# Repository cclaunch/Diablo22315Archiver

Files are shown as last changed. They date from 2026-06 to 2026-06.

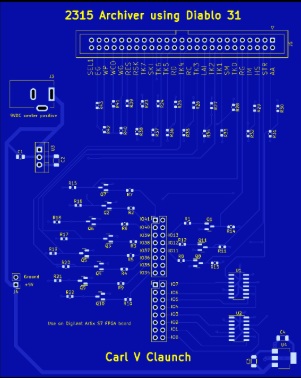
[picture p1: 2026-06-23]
board.jpg

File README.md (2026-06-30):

Diablo disk drive model 31, in its standard density version, can read or write to the 2315 disk cartridges interchanngeably with the disk drives in the IBM 1130 system 

This project exploits an FPGA board with a custom interface board to control the Diablo disk drive. It will read the contents of the disk cartridge into RAM on the FPGA board. 

It then uploads the contents over the USB serial link so that the contents can be archived. The software will take the data streaming over the USB link and create disk files 
in the format used with the IBM 1130 simulator programs (and therefore with the Virtual 2315 Cartridge Facility to access them on a real 1130 system. 

The PCB connects to the FPGA board, provides power to the FPGA and the logic on the PCB, and connects to the Diablo disk drive using an IDC 50 pin cable.

A PCB is available to create the Head Adapter Tool used in aligning a Diablo 31 standard density drive using the CE Cartridge

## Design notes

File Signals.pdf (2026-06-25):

Signal | Direction FPGA pin | Diablo | Connected IDC50 pin drive pullup terminator pcb term unused Option only
Strobe_L | T | 11 | SS | X | 4 | 220/510 | 10K
Head_Select_L | T | 12 | AA | X | 6 | 220/510 | 10K
Rd_Gate_L | T | 13 | E | X | 10 | 220/510 | 10K
Track7 | T | 34 | BB | X | 36 | 220/510 | 10K
Track6 | T | 35 | T | X | 32 | 220/510 | 10K
Track5 | T | 36 | FF | X | 30 | 220/510 | 10K
Track4 | T | 37 | X | X | 26 | 220/510 | 10K
Track3 | T | 38 | J | X | 22 | 220/510 | 10K
Track2 | T | 39 | RR | X | 18 | 220/510 | 10K
Track1 | T | 40 | N | X | 16 | 220/510 | 10K
Track0 | T | 41 | LL | X | 12 | 220/510 | 10K
Write_Clk_Data_L | T | 10K pullup | B | X | 44 | 120/300 | 10K | X
Restore_L | T | 10K pullup | VV | X | 40 | 220/510 | 10K | X
Write_Gate_L | T | 10K pullup | EE | X | 42 | 120/300 | 10K | X
write protect | T | 10K pullup | H | X | 46 | 220/510 | 10K | X | X
erase gate | T | 10K pullup | K | X | 48 | 220/510 | 10K | X | X
Select 4 | T | 10K pullup | Z | | | 220/510 | | X
Select 3 | T | 10K pullup | V | | | 220/510 | | X
Select 2 | T | 10K pullup | R | | | 220/510 | | X
Select 1 | G | ground | L | X | 50 | 220/510 | grounded
ground | G | ground | D, DD, WW | X | odd #s
Ready_Seek_L | F | 0 | F | X | 38 | 5V/10K | 120/300
Seek_Incomp_L | F | 1 | TT | X | 34 | 5V/10K | 120/300
Rd_Data_L | F | 2 | C | X | 28 | 3V/diode | 120/300 | 120/300
Rd_Clk_L | F | 3 | A | X | 24 | 3V/diode | 120/300 | 120/300
Log_Addr_Inlk_L | F | 4 | XX | X | 20 | 5V/10K | 120/300 | X
SM_L | F | 5 | W | X | 14 | 3V/diode | 120/300
IM_L | F | 6 | Y | X | 8 | 3V/diode | 120/300
Addr_Ack_L | F | 7 | NN | X | 2 | 5V/10K | 120/300
File_Ready_L | F | U | 5V/10K | X
Write_Check_L | F | HH | 5V/10K | X
Sector4 | F | UU | 5V/10K | X
Sector 3 | F | MM | 5V/10K | X
Sector 2 | F | KK | 5V/10K | X
Sector 1 | F | JJ | 5V/10K | X
Sector 0 | F | CC | 5V/10K | X

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
t in

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
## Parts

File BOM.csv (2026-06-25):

# | QUANTITY | VENDOR | DESCRIPTION | UNIT PRICE | EXTENDED PRICE | PART NUMBER | MANUFACTURER PART NUMBER
1 | 20 | Digikey | TRANS NPN 15V 0.2A SOT23-3 | $0.12 | $2.40 | MMBT2369ALT1GOSCT-ND | MMBT2369ALT1G
2 | 20 | Digikey | RES 330 OHM 5% 1/4W 0603 | $0.09 | $1.70 | 10-ERJ-UP3J331VCT-ND | ERJ-UP3J331V
3 | 10 | Digikey | IC BUFF 1.65V 14-SO | $0.23 | $2.33 | 74LVC125AS14-13DICT-ND | 74LVC125AS14-13
4 | 2 | Digikey | CONN HEADER VERT 16POS 2.54MM | $5.56 | $11.12 | 612-TD-108-G-A-ND | TD-108-G-A
5 | 1 | Digikey | IC REG LINEAR 3.3V 800MA SOT-223 | $1.57 | $1.57 | LM1117MP-3.3/NOPBCT-ND | LM1117MP-3.3/NOPB
6 | 1 | Digikey | CONN HEADER VERT 50POS 1.27MM | $2.79 | $2.79 | 2057-HBHR-A1-50-VG-HT-ND | HBHR-A1-50-VG-HT
7 | 5 | Digikey | CAP TANT 10UF 10% 16V 1206 | $0.47 | $2.35 | 478-8235-1-ND | F931C106KAA
8 | 5 | Digikey | CAP TANT 0.33UF 20% 20V 0805 | $0.34 | $1.70 | 718-2503-1-ND | TMCP1D334MTRF
9 | 5 | Digikey | CAP TANT 0.1UF 10% 20V 1206 | $0.89 | $4.45 | 478-TAJS104K020RNJCT-ND | TAJS104K020RNJ
10 | 1 | Digikey | CONN POWER JACK SOLDER 2.5MM | $1.02 | $1.02 | 2092-KLDHCX-0202-BC-1-ND | KLDHCX-0202-BC-1
11 | 2 | Digikey | CONN HEADER VERT 2POS 2.54MM | $0.68 | $1.36 | 612-TS-102-T-A-ND | TS-102-T-A
12 | 25 | Digikey | RES SMD 10K OHM 1% 1/10W 0603 | $0.02 | $0.38 | CR0603-FX-1002ELFCT-ND | CR0603-FX-1002ELF
13 | 10 | Digikey | RES SMD 120 OHM 5% 1/3W 0603 | $0.06 | $0.58 | P120BZCT-ND | ERJ-PA3J121V
14 | 25 | Digikey | RES 300 OHM 5% 1/3W 0603 | $0.05 | $1.36 | RHM300DCT-ND | ESR03EZPJ301
15 | 0.08333 | Amazon | LM7805CV voltage regulator | $6.41 | $0.53 | https://www.amazon.com/dp/B0C5M51R2Z?ref=ppx_yo2ov_dt_b_fed_asin_title&th=1
16 | 1 | Amazon | IDC 50 pin cable | 50cm long | $10.69 | $10.69 | https://www.amazon.com/dp/B07S9KRBDV?ref=ppx_yo2ov_dt_b_fed_asin_title
17 | 1 | ? | Diablo terminator |  |  | collectors or ebaty
18 | 1 | ? | Diablo model 31 standard density |  |  | collectors or ebaty
19 | 1 | Digilent.com | Artix S7 FPGA board | $127.33 | $127.33 | https://digilent.com/shop/arty-s7-spartan-7-fpga-development-board/
20 | 1 | Amazon | 9V power supply wallwart | $9.62 | $9.62 | https://www.amazon.com/dp/B087ZWS7CG?ref=ppx_yo2ov_dt_b_fed_asin_title&th=1
21 | 1 | PCBway | PCB manufactured from design | $174.99 | $174.99
22 | 2 | Amazon | Meanwell 15V 7A PS bought as pair | $19.71 | $39.42 | https://www.amazon.com/dp/B0CCYL43VT?ref=ppx_yo2ov_dt_b_fed_asin_title&th=1
23 | 1 | Amazon | Dual +/- 15V 2A supply | $30.17 | $30.17 | https://www.amazon.com/Output-Switching-Converter-Computer-24V1-6-24V1-6A/dp/B0DSFLLWTV
 |  |  |  | Total | $427.86

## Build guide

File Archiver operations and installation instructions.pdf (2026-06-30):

## Operations and Installation Instructions

2315 Archiver on Diablo 31 Drive

Carl V Claunch | 1 | Version 1

Archiving 2315 cartridges for the IBM 1130 System

The IBM 1130 System uses a single 14” platter disk cartridge (2315) inserted into an internal disk drive (13SD or Ramkit) or the optional 2310 external disk drive cabinet.

The 2315 cartridges record up to 512K words in sectors of 321 words each. The disk is organized into 203 cylinders, with an upper and a lower surface (track) per cylinder and having four sectors on each track. The platter is inside a protective plastic case.

The data is recorded at a rate of 720 kilobits per second while the disk platter spins at 1500 rpm. Thus data streams to and from the drive at 36K words per second during a read or write.

Each 16 bit word is recorded with four additional error checking bits. There is a mandatory preamble and a sync word at the start of each sector. The format for a sector is unique to the IBM 1130 and 1800 systems.

2315 Archiver on Diablo 31 Drive

Carl V Claunch | 2 | Version 1

IBM licensed disk drive technology to multiple companies

IBM offered licenses to other manufacturers who produced disk drives and disk cartridges based on the 13SD drive and 2315 cartridge designs. Several firms made disk cartridges and several developed disk drives for their minicomputer systems under license.

The 2315 cartridge used with the IBM 1130 has eight physical sectors around the circumference of the platter, but licensees made versions with other sector counts, up to 32. The platter is otherwise identical except for the metal hub with its sector mark notches.

The companies that licensed the disk technology were free to improve on the 13SD drive and most did. The IBM drive used a mechanical ratchet system for arm movement between cylinders, thus is moved in steps of 1 or 2 cylinders at a time. All the other manufacturers designed a servo system that supports a single move of any number of cylinders.

The rate at which data is clocked onto the platter - 720KHz in the case of the IBM drive - was implemented at higher rates of 781, 1440 and 1562 KHz by those makers. The two higher rates were labeled High Density.

Other versions doubled the number of cylinders on a pack by writing narrower tracks and moving in finer increments. A few added a second fixed platter underneath the place where the cartridge’s platter spins. Thus the licensees could achieve more than 16 times the data density of the 13SD and 2315 used in IBM 1130 systems.

2315 Archiver on Diablo 31 Drive

Carl V Claunch | 3 | Version 1

Diablo Model 31 Drives

Diablo Systems built their Model 30 series under license and in particular sold the Model 31 as the closest version to the IBM 13SD/2310. They offered many options - Model 31 could operate at any of the four data rates and make use of cartridges with 8, 12, 16, 24 or 32 sectors per revolution. Xerox PARC (Palo Alto Research Center) created their groundbreaking Alto computers using a high density model 31 drive.

Model 31 drives can be used with this project to read 2315 cartridges that were written on IBM 1130 systems, but must match the specifications of the 13SD drive. Thus, they must use 8 sector cartridges and have a data rate of 720KHz. If so, the Diablo drive and the 1130 can read data written on the other system, giving full interchangeability.

The Model 31 must have certain options listed to be compatible with the 13SD. Essentially, they must be a standard density version, at either 720KHz or 781KHz data rate.

Modifications to the printed circuit boards inside the Diablo drive can change a 781KHz drive into the desired 720Khz for compatibility, but option 001 (720KHz) works without modification. Details of the modification are provided later in this document.

Options26 39, 40, 41, 42, 51, 52, or 54 indicate drives that are based on more sectors than the 8 per revolution used with the IBM drives. The other options may slightly change the electrical interface but don’t affect the physical interchangeability of cartrdiges between IBM and Diablo.

2315 Archiver on Diablo 31 Drive

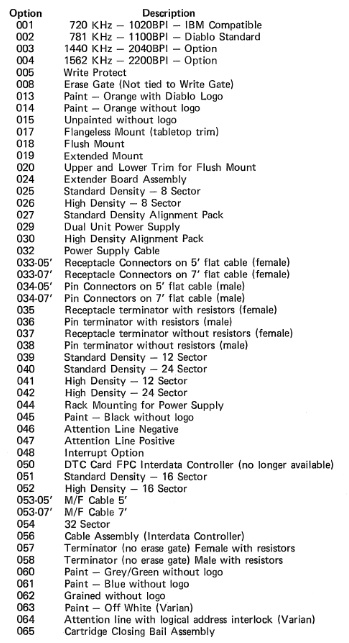
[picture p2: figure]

Carl V Claunch | 4 | Version 1

This is the full option list for Model 31 drives:

2315 Archiver on Diablo 31 Drive

Carl V Claunch | 5 | Version 1

Interface to Model 31 drive

The electrical interface to the Diablo model 31 differs from the IBM 13SD drive, mainly due to the change in arm movement between the IBM drive and the way that licensees like DEC, HP and Diablo implemented seeks.

The handshakes between the controller logic and the disk drive are different as well as having an absolute cylinder number and different movement command signals. Thus this cannot use the logic designed to read or write on the 13SD drives.

The Diablo drives can be daisy chained with up to four drives connected to a single controller, making use of four Select signals to control which drive is active at any instant. A terminator is installed on the back of the last drive in a chain. Terminators vary based on some options, thus when using this project, the builder must verify that the critical signal lines have termination resistors; the terminator must be modified if it does not match.

This project includes a printed circuit board that supports the electrical requirements of the interface to the Diablo Model 31, including termination resistors for the controller side of the cable. A standard 50 pin IDC connector (e.g an internal SCSI cable for a PC) is used to connect a cable from the PCB to the connection block of the Diablo Model 31 disk drive. This requires changes to the cable and connection of the wires in the cable to the proper pins on the disk drive.

2315 Archiver on Diablo 31 Drive

Carl V Claunch | 6 | Version 1

Components of the archiver project

A suitable Diablo Model 31 disk drive is required. A terminator and a signal connector are also needed, although the connector will be modified in all cases.

A Digilent Artix A7 FPGA board with the bitstream from this project loaded onto the board to implement the logic of the project.

A custom PCB installed on top of the FPGA board to provide the electrical interface between the FPGA and the Diablo drive.

A modified 50 pin IDC flat ribbon cable runs between the PCB and the Diablo drive connector.

A USB cable to provide a serial link to a PC, Mac or other computer where the data extracted from the 2315 cartridge can be uploaded.

A Python application that connects to the archiver and creates disk files in the format used by the IBM 1130 simulator programs. This is the standard for interchange of disk cartridge images.

2315 Archiver on Diablo 31 Drive

Carl V Claunch | 7 | Version 1

Operating the Archiver

With the disk drive and the power supply of the Archiver both plugged into the building AC mains, the device is ready to perform archiving.

It is highly recommended to open each 2315 cartridge before reading it, inspecting for damage, and cleaning the surfaces with 91% Isopropyl Alcohol and low/no lint wipes. This minimizes the risk that you will suffer a head crash which scapes up the disk heads in the Diablo drive and perhaps damages the 2315 cartridge platter.

Eight screws around the bottom of the cartridge are removed to open the cartridge case and expose the platter inside. Use disposable gloves when handling the platter as a fingerprint is high enough to cause a head crash if you touch the surface of the platter

The heads should also be inspected with a dental mirror before archiving each cartridge, looking for the buildup of oxide or signs of a head crash. Low lint swabs with 91% Isopropyl Alcohol can be used to clean the heads, although with crashes it may be necessary to remove the heads for a more complete cleaning and then perform an alighment on reinstallation.

Insert the cartridge into the Diablo drive and switch on the drive. I recommend repeatedly spinning the drive for about 30 seconds and shutting down to ensure all dust is removed first. The drive has a HEPA quality filter that should clean the air going into the cartridge, but it may take some time to get all residual dust out before we want to load the heads.

The cartridge should come up to speed and after 50 seconds, the Ready lamp on the drive illuminates indicating that the heads have been lowered onto the spinning disk surface.

2315 Archiver on Diablo 31 Drive

Carl V Claunch | 8 | Version 1

With the righrmost slide switch SW0 on the FPGA board set to the lower position, push the rightmost button BTN0 to begin the archiving process. LEDs will light with various status and error conditions - see the troubleshooting section later for details.

You will hear the Diablo drive moving the disk arm cylinder by cylinder as it reads all 203 cylinders into memory on the board. When it is complete, power down the Diablo drive and remove the 2315 cartridge.

Start the python application, choose a file location and name for the archived disk image, and wait until the application tells you it is ready.

Move slide switch SW0 to its top position and then push the button BTN0 to start the upload process. When the contents have been successfully loaded, the application will indicate success and you can move the rightmost slide switch back to the bottom position to prepare for the next cartridge to be archived.

The application will report any sectors that experienced data errors during the archiving. Since cylinders 200, 201, 202 and 203 are reserved as alternate cylinders for any of the first 200 that might have imperfections, you may see errors on some cylinders that were either defective or alternates that were not used nor formatted.

Note any errors just in case some content of the cartridge was not recovered properly. Deal with the error sectors manually using an IBM 1130 simulator and disk utilities, after first excluding defective and unused cylinders.

2315 Archiver on Diablo 31 Drive

Carl V Claunch | 9 | Version 1

Building the cables between the archiver PCB and the Diablo drive

On the rear of the Diablo drive are a pair Winchester MRAC 42 plug and socket connectors and a Winchester MRAC-14S socket. The 42 pin parts are for signals while the 14 pin part delivers power.

Power connector

The power connector has letters A to F, H, J to N, P and R arranged left to right, from top to bottom looking at the face of the connector. Connect ground to pin C, high current (4A average 8A peak) +15V power supply to K, high current (4A average 8A peak) -15V power supply to R, low current +15V supply to H and low current -15V power supply wire to P. Use 16 ga wire for power and at least 15ga braid ground wire.

Noise generated by motors and servos will be fed back on the high current supplies, which is why a separate low current version is needed for signaling and logic.

Signal connector

There is a 42 position male (pins) and a female (sockets) connector on each drive. The terminator assembly is connected to one of them and the cable to the archiver connects to the other. The corresponding pins of both connectors are wired together thus the only difference is gender.

The connectors can be found on eBay, both the 42 pin shell and the male or female inserts for each position. Take a 50 cm 50 wire flat ribbon cable that has the IDC (internal SCSI) connectors installed. Remove on of the two IDC connectors and separate the wires. Every other wire in the cable is connected to ground on the archiver PCB.

2315 Archiver on Diablo 31 Drive

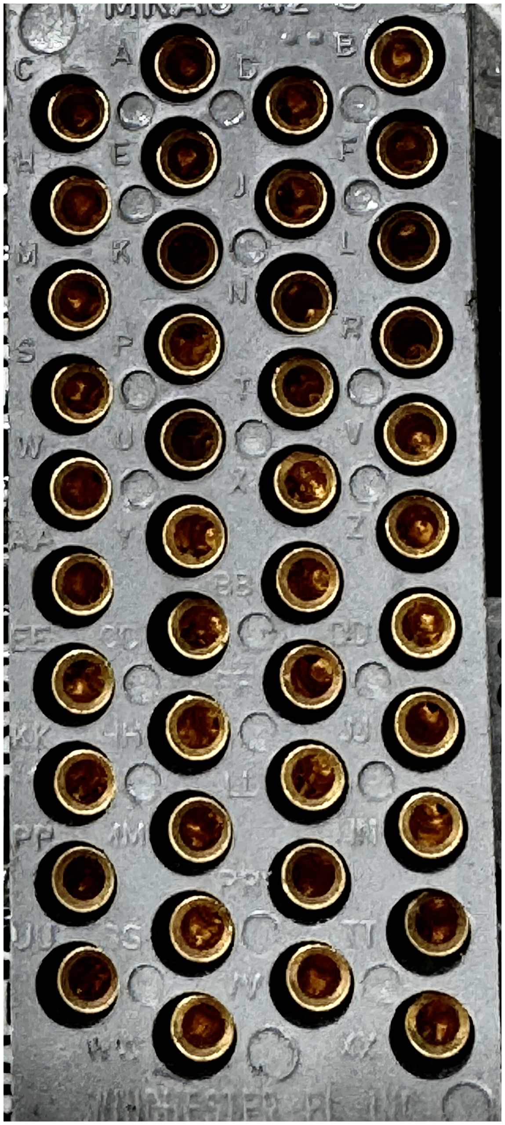
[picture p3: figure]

Carl V Claunch | 10 | Version 1

The positions on the MRAC connector are labeled with single or double letter codes - A to F, H, J to N, P, R to Z, AA to FF, HH, JJ to NN, PP, and RR to XX running left to right, from top to bottom as you look at the male connector face.

2315 Archiver on Diablo 31 Drive

Carl V Claunch | 11 | Version 1

Connect wires 1 and 3 to pin D, wires 23 and 25 to pin DD and wires 47 and 49 to pin WW which establishes the ground connection to the drive. Then connect the following wires to these pins:

2 | - NN
4 | - SS
6 | - AA
8 | - Y
10 - E
12 - LL
14 - W
16 - N
18 - RR
20 - XX *
22 - J
24 - A
26 - X
28 - C
30 - FF
32 - T
34 - TT
36 - BB
38 - F
40 - VV
42 - EE
44 - B
46 - H *
48 - K *
50 - L

Wires 46 and 48 are attached only if the write protect (option 005) and erase gate (option 008) are installed on this drive.

If options 046, 047 or 064 are installed, do not connect wires 20 and 46.

2315 Archiver on Diablo 31 Drive

Carl V Claunch | 12 | Version 1

Power supply sourcing

The drive requires four separate power supplies, two at +15VDC and two at -15VDC. One of each is a high current version, delivering a steady 4A with temporary bursts as the motor starts to spin. The other two deliver 2A of current for the logic and analog circuits that need to be free from the noise and impedance effects of the heavy current loads.

I bought three supplies, two are high current single voltage and the third delivers both +15V and -15V at lower current. These connect to the 120VAC mains. I found these on Amazon.com and should have them in a few days so that I can spin up the drive.

2315 Archiver on Diablo 31 Drive

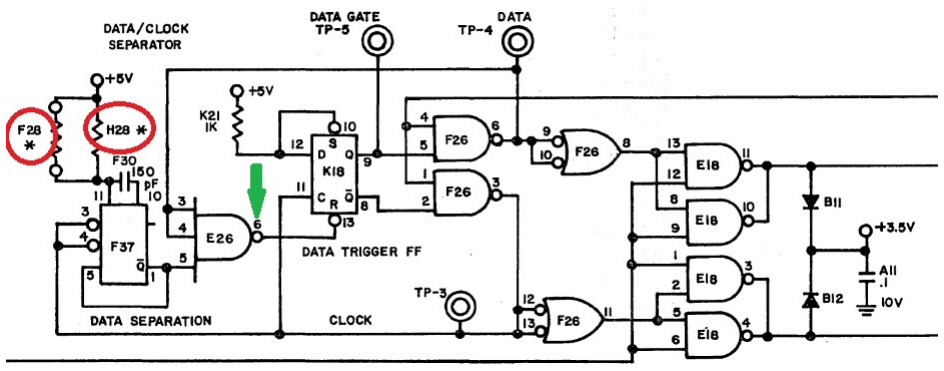
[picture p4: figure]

Carl V Claunch | 13 | Version 1

Modifying the Diablo Model 31 if option 002 (781KHz)

Pull out PCB J10 from the Diablo Model 31 drive’s card cage. Verify it is the Standard Density version, not the 1440 or 1562KHz high density alternative which has a board number of 11082-xx.

The PCB board number will be 11113-04, 11113-05, 11113-06 or 11113-07 if it is the standard density 781KHz data rate board.If the PCB number is 11113-00, 11113-01, 11113-02 or 11113-03 then it is already the IBM compatible 720KHz design.

The four subtypes depend on if there is an independently controlled Erase Gate signal (option 008)and if it is designed for daisy-chaining up to four drives from the controller. The first and second are for machines with no daisy chain, which means no Selection jumper used; I have never seen one without daisy chaining. Thus you have the fourth type if option 008 is installed, otherwise the third type.

To convert the data rate down from 781KHz to 720KHz, you change the resistor at H28 from a 9.08K to a 10K 1/2W 5% part. You then trim the resistance by selecting a high value parallel resistor F28 so that the data gate signal, the output of gate E26, is high between 955 and 985 nanoseconds duration. The faster board had a shorter gate duration (882-912ns).

2315 Archiver on Diablo 31 Drive

Carl V Claunch | 14 | Version 1

Troubleshooting

The FPGA board has eight LEDs that provide status information about the archiver operation - LD4 to LD7 are single color while LD0 to LD3 are tricolor and can show up to three signals per LED.

Displayed in both archive and upload

LD0 has red on head 1 is selected, off if head 0 LD0 has green on if the sector number is odd LD0 has blue on if the sector number is 2 or 3

LD1 is blue if the arm is at cylinder 0 to 22 LD1 is green if the cylinder is 23 to 45
LD1 is red if the cylinder is 46 to 68

LD2 is blue if the cylinder is 69 to 91
LD2 is green if the cylinder is 92 to 114 LD2 is red if the cylinder is 115 to 147

LD3 is blue if the cylinder is 148 to 170
LD3 is green if the cylinder is 171 to 193
LD3 is red if the cylinder is 194 to 203

The signals displayed can vary based on the position of the rightmost slide switch SW0 where the down position is during archiving and the up position is during upload of the captured disk image.

2315 Archiver on Diablo 31 Drive

Carl V Claunch | 15 | Version 1

Displayed during archiving

LD4 illuminates after power-on of the FPGA once the dynamic RAM on the board has finished its initialization and calibration. If this is not on, the archiver will not do anything.

LD5 is lit when the driver reports a logical address interlock - a seek attempt to a cylinder beyond 203. Most drives do not have this signal active so this would never light on those

LD6 is lit when a seek to a cylinder fails, which results in the drive becoming locked until it is power cycled. This is a hardware failure.

LD7 is lit when the archiving is complete - all 1, 632 sectors have been read and saved in RAM.

Displayed during uploading

LD4 illuminates when the FPGA has initialized and calibrated RAM so that it is ready to work. If this is not on, no other function works.

LD5 is lit when the upload process has completed, transferring all 1, 632 sectors of data over the USB serial link.

LD6 should not light in upload. It indicates that the disk drive suffered an error during a seek and has locked up, requiring power cycling.

LD7 is lit if the prior archiving process completed

2315 Archiver on Diablo 31 Drive

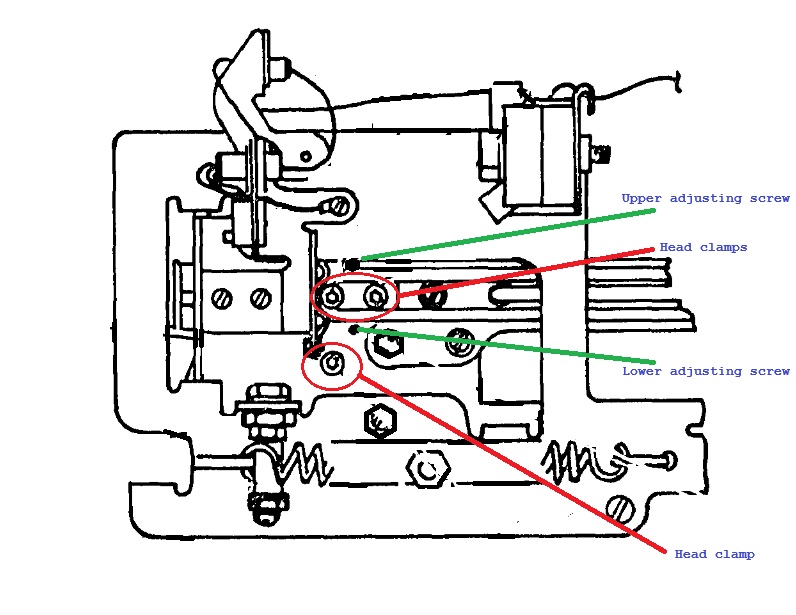
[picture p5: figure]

Carl V Claunch | 16 | Version 1

Adapter board to support alignment of the Diablo disk drive

The heads of the disk drive are attached to an arm that is moved in and out to reach each of the 203 cylindrical recording positions on the platter. When a head is installed, it must be adjusted so that it rides precisely over the intended track on the platter. This is important to allow data written on one disk drive to be successfully read from another drive.

A special 2315 cartridge, called the CE Cartridge, has a special pattern recorded at cylinder 100 which is used to fine tune the location of the head, using an oscilloscope to watch the signal returned from the read circuitry.

The heads are clamped in place and have a diagonal notch that a setscrew pushes into that will force the head slightly forward with each turn of the screw.

However, in order to maximize the visibility of the pattern on the scope, standard density heads needed to use the erase coil of the head, whose magnetic poles were further apart than the read/write coils.

2315 Archiver on Diablo 31 Drive

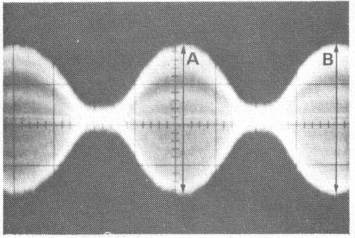
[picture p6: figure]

Carl V Claunch | 17 | Version 1

To switch over to using the erase coils, a special adapter is plugged into the drive, sitting between the cable from the heads and the J10 printed circuit board that contains the read amplifiers. This was called the Head Adapter Tool and I have never seen one of these in the last decades.

I designed a small PCB to act as a Head Adapter Tool. Its design is included in the project, allowing anyone with a Diablo standard density drive and a CE cartridge to complete the alignment procedure as defined by Diablo.

The alignment is complete when the signal pattern, consisting of multiple lobes and null points, displays lobes with as close to identical amplitudes as possible. That indicates that the head is right over the centerline of track 100.

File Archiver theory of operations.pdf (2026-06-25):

## Theory of Operation

2315 cartridge archiver using Diablo 31

Carl V Claunch | 1 | Version 1

Summary

This project employs a Diablo Systems model 31 disk drive of either 720 Khz or 781 KHz data rate to read the contents of 2315 disk cartridges that were used on an IBM 1130 system. It then uploads the archived contents over a USB serial link to an application running on a PC, Mac or other computer that will store the disk image in the format used with the IBM 1130 simulators.

This is based around a Digilent Arty A7 FPGA board, having a Xilinx Artix A7 FPGA, plenty of dynamic RAM, buttons, switches, LEDs and quite a few input-output connections.

A custom printed circuit board is plugged into the top of the Arty A7 board. It is powered by a wall wart 9V DC supply and in turn feeds the appropriate power to the circuits on the PCB as well as to the FPGA board. The board interfaces with the voltage, impedance and current requirements of the Diablo disk drive on one side and the FPGA board on the other.

A 50 pin IDC connector on a flat ribbon cable, modified on one end to connect to the Diablo drive Winchester MPAC-42 connector, carries signals between the custom PCB and the drive.

Three 120V power supplies deliver the +15V and -15V power to the high current and low current connections on the disk drive using a Winchester MPAC-9 connector. A USB cable connects the FPGA board to the remote computer that is running the Python application supplied with the project.

2315 cartridge archiver using Diablo 31

Carl V Claunch | 2 | Version 1

IBM 13SD disk drive as used in the IBM 1130

The IBM 1130 System uses a single 14” platter disk cartridge (2315) inserted into an internal disk drive (13SD or Ramkit) or the optional 2310 external disk drive cabinet.

The 2315 cartridges record up to 512K words in sectors of 321 words each. The disk is organized into 203 cylinders, with an upper and a lower surface (track) per cylinder and having four sectors on each track. The platter is inside a protective plastic case.

The data is recorded at a rate of 720 kilobits per second while the disk platter spins at 1500 rpm. Thus data streams to and from the drive at 36K words per second during a read or write.

Each 16 bit word is recorded with four additional error checking bits. There is a mandatory preamble and a sync word at the start of each sector. The format for a sector is unique to the IBM 1130 and 1800 systems.

IBM software systems use only 200 cylinders for the data. The remaining four cylinders are spares. When the disk cartridge is being initially formatted, if testing determines that a spot on a cylinder cannot successfully write and read back data, the cylinder is marked as defective and one of the four spares is assigned instead.

The software using the cartridge reads the table of possible alternate cylinders when the cartridge is first mounted, then converts any movement to the defective cylinder to the assigned alternate.

The disk arm has two heads, one for each side of the 14” platter. It can move outward towards cylinder 0 or inwards towards cylinder 203, but only in steps of 1 or 2 cylinders from its current location. A microswitch confirms when the arm has reached cylinder 0 (the home cylinder).

2315 cartridge archiver using Diablo 31

Carl V Claunch | 3 | Version 1

Moving the arm involves setting the step size (-10mil) and direction (-Reverse) signals, then commanding a movement (Access Go). Feedback signals (Access Ready) indicate that the drive has begun the movement and then tells us when the arm is steady at the new cylinder.

Notches cut around the circumference of the disk cartridge hub define the beginning of each pie shaped slice of the platter. There are eight notches however the 1130 controller converts those eight sectors into four larger sectors which is what the software sees when it uses the drive.

Pulses arrive on the interface - a Sector Marker - when we reach each notch. A separate notch defines the start position. This is the Index Marker and lets us know that the next sector is to be considered sector 0.

The interface has a control signal called Read Gate which switches on the electronics to deliver pulses coming from the head as it rotates through the sector. The data on the sector is recorded serially at a rate of 720 KHz.

The drive uses a self clocking scheme since all we see from the disk surface is when the magnetic field is reversed.

2315 cartridge archiver using Diablo 31

Carl V Claunch | 4 | Version 1

Reading if using the 13SD drive

If we wanted to read the contents of the disk cartridge using the 13SD drive, we would access it via its simple interface. For simplicity of understanding, you can consider the 720KHz clock to be divided into two halves - high then low.

During the high portion of a clock cycle, we always record a magnetic reversal. This is the clock pulse. During the low portion of the clock cycle, we either record another magnetic reversal or we leave that spot along. If the reversal comes in the low portion of the clock, we term this a data bit value of 1. No reversal in the low portion means that we have a data bit value of 0.

The beginning of every sector consists of a long stream of 0 data bits -each having a reversal only in the high portion of the clock. The long stream allows the drive electronics to synchronize to this pattern and begin splitting the reversal pulse out over two different output lines.

The clock pulse comes out on the Read Clock interface line, while any pulses from the low portion of the clock cycle are emitted on the Read Data line. We can watch for any data pulse that occurs betweee successive clock pulses and consider that a data bit value of 1, otherwise when we see the next clock pulse we consider that we received a data bit value of 0.

This self-synchonizing scheme tells us how to split clock and data pulses as they are picked up by the read head, but we don’t yet have a way to identify the first bit of an 1130 word. The 1130 uses 16 bit long words, thus we are extracting 16 data bit values to form a word.

2315 cartridge archiver using Diablo 31

Carl V Claunch | 5 | Version 1

For error checking purposes, the controller logic actually records 20 bits for each word. The last four bits are a value that brings the count of 1 data bits in the word to an even multiple of four. If the 16 bit 1130 word was already at an even mulitple of four - for example values x0000, x0238 and xffff have 0, four and sixteen 1 bits thus all are an even multiple of four. Our check bits would be 0000

The check bits are emitted to bring the count of 1 bits up to 0 modulo 4. For example, if we had the word x8000 with a single 1 bit, then the first three check bits are 1 and the last is 0, bringing the count up to 4.

To know when we are beginning a word recorded as 20 bits, we need to delineate when the first data bit would occur. that could be a 0 data value or a 1, so we have a special word value which is the first word recorded after the long string of 0 data bits. This word is x0001 with check bits 1110.

The logic reading from the drive turns on the Read Gate when we reach the sector, waits for a while to let the string of 0 data bits syncrhonize the clock/data splitter, then we watch for a data word that is the bit pattern 00000000000000011110 and the very next data bit will be the first bit of the first word of the sector.

The sector has up to 321 words of data recorded on it - 6,420 clock pulses, which we can now separate into words because we are synchronized. Typically we turn off the Read Gate after we read the last word. The 1130 can request from 1 to 321 words to be read, thus that count is used to decide when to turn off the Read Gate. For most purposes the 1130 reads all 321 words of a sector.

2315 cartridge archiver using Diablo 31

Carl V Claunch | 6 | Version 1

We have a Head Select signal that tells the drive to read or write from either the top head or the bottom head. Each head rotates past four sectors during one revolution of the disk drive. By reading four sectors on one side, switching the head and then reading another four sectors, we can read all 2,568 words of that cylinder.

Setting the direction and step size first, we can ask the disk drive to move the arm its 1 or 2 cylinders. When the feedback tells us we are at our new cylinder location, we can read or write the sectors at that arm position.

Writing new contents into a sector involves using the Write Gate, Erase Gate and the Write Clock & Data signal lines. When the Sector Mark indicates we are at the intended sector position, we turn on the Write and Erase Gate lines. We begin emitting a string of pulses on the Write Clock & Data signal line at 1,440 KHz rate. We alternate a clock pulse with either a data pulse or no pulse, so that we are generating the self clocking stream of magnetic reversals on the disk.

We begin by sending out only pulses for the clock portion, thus we write a long string of 0 data bits. When ready, we write a stream of pulses on
Write Clock & Data - 1 0 1 0 1 0 1 0 1 0 1 0 1 0 1 0 1 0 1 0 1 0
1 0 1 0 1 0 1 0 1 1 1 1 1 1 1 1 1 0 - which represents data bit val-
ues 0 0 0 0 0 0 0 0 0 0 0 0 0 0 0 1 1 1 1 0 or our sync pattern
word. We then write out the data words, first the sixteen data bit values as either 1 1 or 1 0 depending on the bit value, followed by the check bit pattern to bring our count of 1 value data bits to an even multiple of four.

When we have written the last word we want on that sector, we turn off the Write Gate and the Erase Gate control lines. Typically, all 321 words are written to a sector by 1130 software.

2315 cartridge archiver using Diablo 31

Carl V Claunch | 7 | Version 1

The only other signals on the interface are File Ready - the drive is ready to read/write/seek - a 720KHz clock which is generated in side the disk drive, and a 90 second delay signal that lets us know that the drive started but has not yet allowed enough time to purge any dust or contaminents from the surface of the disk. After 90 seconds the drive lowers the heads onto the disk surface and they ride at cylinder 0 waiting for commands over the interface.

2315 cartridge archiver using Diablo 31

Carl V Claunch | 8 | Version 1

Diablo Systems model 31 disk drive

IBM offered licenses to other manufacturers who produced disk drives and disk cartridges based on the 13SD drive and 2315 cartridge designs. Several firms made disk cartridges and several developed disk drives for their minicomputer systems under license.

The companies that licensed the disk technology were free to improve on the 13SD drive and most did. The IBM drive used a mechanical ratchet system for arm movement between cylinders, thus is moved in steps of 1 or 2 cylinders at a time. All the other manufacturers designed a servo system that supports a single move of any number of cylinders.

The rate at which data is clocked onto the platter - 720KHz in the case of the IBM drive - was implemented at higher rates of 781, 1440 and 1562 KHz by those makers. The two higher rates were labeled High Density.

Diablo Systems was one of the companies that built drives which were used by computer makers such as Xerox, Varian, and Interdata. Other companies such as DEC and HP licensed the technology and made their own drives.

The Diablo Model 31 comes in many flavors, described by the Options configured on the drive. Option 001 was for standard density 720KHz operation, also called IBM compatible.

Model 31 could operate at any of four data rates (720KHz, 781KHz, 1440 KHz and 1562KHz) and make use of cartridges with 8, 12, 16, 24 or 32 sectors per revolution. Xerox PARC (Palo Alto Research Center) created their groundbreaking Alto computers using a high density model 31 drive.

2315 cartridge archiver using Diablo 31

Carl V Claunch | 9 | Version 1

Using Diablo drive to read 1130 cartridges

Model 31 drives can be used with this project to read 2315 cartridges that were written on IBM 1130 systems, but must match the specifications of the 13SD drive. Thus, they must use 8 sector cartridges and have a data rate of 720KHz. If so, the Diablo drive and the 1130 can read data written on the other system, giving full interchangeability.

We provide a way to modify a Model 31 from Option 002 - 781KHz data rate - so that it can operate at the 720KHz rate. The higher density options use a different kind of read/write head and are incapable of interchanging data with the 13SD drive.

The interface of the Diablo Model 31 is more complex than the 13SD, plus there are many options to suit the many manufacturers who used these drives with their computers. A key difference is in how the disk arm is moved to a desired cylinder.

The Diablo interface has a set of eight signal lines (Track) that specify an absolute cylinder location. It does not have a direction or a step size. Instead, the interface is given the destination cylinder and then the Strobe signal is activated to request the movement. No home cylinder microswitch signal is included because the drive always knows here it is.

The feedback mechanism for a seek is a bit more complex - with timing requirements for when the Ready to Seek, Read or Write signal must drop and when it turns back on at the end of a movement. An Address Acknowledgement signal is sent to inform the computer that the drive has accepted the movement request.

Failure of the seek mechanism is indicated by Seek Incomplete. Requests to move to a cylinder beyond 203 can trigger a Logical Address Interlock signal if that option is included on the drive.

2315 cartridge archiver using Diablo 31

Carl V Claunch | 10 | Version 1

Sector Mark and Index Mark pulses are generated just like wtih the 13SD. However, this does require that the drive is configured for 8 sectors and the 2315 Disk Cartridge is 8 notches cut around the hub. Diablo also supports 12, 16, 24 and 32 sector formats which are incompatible with IBM.

Besides the use of the Sector Mark and Index Mark pulses, the interface offers a five bit Sector Number field that reports the upcoming sector number directly. There is also a Pseudo-Sector Marksd which emits pulses at a 50KHz rate so that a computer interface can calculate its own logical sector lengths, disregarding the phsical notches.

Reading and writing are controlled in very similar ways to the IBM 1130. Read Gate and Write Gate are used the same way. Erase Gate is normally activated automatically when Write Gate is asserted, but an option exists to control them individually. Head Select is used to swtich between the upper and lower sides of the platter.

The drive uses the same self-clocking scheme as the 13SD, thus pulses come out on the Read Clock and Read Data signals just as they do with IBM drives. Writing involves sending the mixed clock and data pulses on Write Clock & Data, again just like the 1130.

There are some signal options such as Write Protect which blocks the drive from erasing or writing, Write Check indicates a failure of the writing electronics and locks up the drive. Restore which brings the arm back to Cylinder 0 and resets any drive error condition.

Finally, the Diablo drives can be daisy-chained off a single disk controller, with up to four drives connected. The interface has signals Select 1, Select 2, Select 3 and Select 4 to allow the controller to choose which drive should respond to its commands. Interrupt and attention signals are also options but only rarely found on the drives.

2315 cartridge archiver using Diablo 31

Carl V Claunch | 11 | Version 1

Logic in the FPGA

Besides offering a boatload of logic elements, the Arty A7 board has 256MB of DDR3 DRAM which is very handy to store the contents of a disk cartridge which itself holds only 1MB of data. The onboard clock crystal runs at 100 MHz, far faster than any events happening on the disk drive (or even in the IBM 1130).

I set up a clock generator to produce the faster clocks required by the DDR3 memory controller intellectual property. In addition to the memory interface IP and the clock IP, I defined two FIFO queues using IP that exploits the native FIFO hardware on the FPGA chip. This is because the memory interface runs at a different clock rate than the general 100MHz logic of my design, thus the FIFO allows the data to cross clock domains safely. The memory interface produces the ui_clk clock used to drive the memory interface.

All external signals run through a chain of four flipflops to protect against metastable states since the timing of signal changes externally is unrelated to the clock edges inside the FPGA. I then pass the through a Schmitt Trigger module I wrote so that brief waggles in signals don’t cause the logic to switch states at the wrong time.

Everything I coded is in Verilog, although the IP and some borrowed modules may be in VHDL. In some ways, it is influenced by the RK05 Emulator code. I split the design into functional modules such as read a sector, seek to a cylinder, track the sector position, and then higher level modules that drive the process of archiving by moving serially through all 1,634 sectors across 203 cylindere.

2315 cartridge archiver using Diablo 31

Carl V Claunch | 12 | Version 1

The top level module just routes signals to the various functional modules and externally. to the interface board. It displays status on the eight LEDs and uses a slide switch and a button to request the archive step and then the upload across the the USB serial link.

Archiver module

The archiver logic starts off at cylinder 0, upper head, sector 0 and word
0. When the button is pressed to start the state machine, it advances through the states until it has completed reading all 1,634 sectors and 521,304 words and storing them into the RAM.

It loops waiting for the sector number to change to the target number, then kicks off the bus_read_drive module to read the sector. When that module responds with a completion signal, the state machine advances.

The next step advances through sectors, from 0 to 1 to 2 to 3, then returns to wait for that sector to arrive. When sector 3 has finished its read, the next step switches the head to the other platter and resets the sector target to 0. It then returns to wait for the sector.

After we finish sector 3 of the second head, we move to a step that advances the cylinder by 1, resets the head and the sector before returning to wait for the sector.

When we have finished the last sector, instead of going back like we did for the first 202 cylinders, we turn on a feedback signal indicating we are done with archiving and then reset to the idle state until we get a new request for archiving.

2315 cartridge archiver using Diablo 31

Carl V Claunch | 13 | Version 1

Sector and Index module

The module watches for the leading edge of the Sector Marker and Index Marker pulses to track the position of the platter as it rotates. It must swallow every other Sector Marker because that is how the 1130 controler logic converts the eight physical sectors into four logical one. The module emits the upcoming sector number to the other modules and a pulse when the Sector Marker leading edge arrives to start that sector.

Seek to Cylinder module

The state machine matches the timing spec of the Diablo model 31 drive. When a Strobe request arrives, the state machine first emits the new Track number to the drive. It then waits for Addr_Ack to be asserted by the drive, then loops for 3 microseconds. After that time, it resets the Track number. The state machine then drops the Strobe signal and waits for the drive’s Ready_Seek to go low, then returns to the idle state.

2315 cartridge archiver using Diablo 31

Carl V Claunch | 14 | Version 1

Bus_Read_drive module

When a requestread signal arrives to read a sector and store the words into the DRAM, the state machine waits for the leading edge clkenable_sector pulse from the Sector and Index module that indicates we reaached the start of a sector.

The first state raises the Read_Gate signal and sets up to wait rhrough reading 100 bit values of 1 from either the Read Clock or the Read Data lines. The preamble should be a long string of clock pulses with no data pulses which allows the drive to properly split pulses as clock or data.

After we see 100 pulses, it is time to move to the state that waits until it sees the special sync word pattern - 0b00000000000000011110 which is a word of single trailing bit of 1 and the correct check bits 0b1110 to reach a multiple of four bits with the value 1.

It is detected when the first 1 value arrives on Read_Data, then it advances to verify that the next four bits are 1 1 1 0. to confirm that it is the sync word. It sets up a word count of 321 words and advances to accumulate the 20 bits of the word ad its check bits. If the sync word wasn’t validated, the syncerror state is recorded.

The logic watches the falling edge of the Read Clock pulse then if it sees a Read Data pulse before the rising edge of the next Read Clock, we set the got_one signal.

We clock in the got_one bit value into a shift register on every rising edge of Read Clock. We also maintain a count of how many 1 bits were detected. After 16 clock pulses we stop shifting the bits in but we continue counting 1 bits for the next four clock pulses, which are the check bits. At the end of the word, we detect an error if the counter doesn’t reach 0 modulo 4.

2315 cartridge archiver using Diablo 31

Carl V Claunch | 15 | Version 1

At the end of the word, it bumps the word number then at the falling edge of the Read Clock pulse, it raises the grabword signal and sets up the data from the shift register for the write to the DRAM.

We go back to read the next word until we complete all 321 words then we save any errors before finishing.

If we saw an error on any word, because the four check bits didn’t advance the ones counter to a multiple of four, we store that condition in word 322. We also store the state of the syncerror state. That allows us to keep track of whether any sectors had errors while being archived.

The state machine sits at the last step, raising readdone to the archiver module and waiting until the archiver drops the requestread signal before we go back to idle.

2315 cartridge archiver using Diablo 31

Carl V Claunch | 16 | Version 1

dram_controller module

This module is responsible for both reading and writing from the
DRAM. The address in DRAM is formed from the cylinder, head, sector and word number. Requests grabword and echoword are the triggers asking this module to write to DRAM or to read from DRAM respectively.

This module works in two different clock domains, the 100 MHz main clock and the ui_clk clock produced by the memory interface generator IP. Any request to read or write memory must be done with the ui_clk clock.

I created two FIFOs to pass information between the two clock domains. The write FIFO takes words from the archiver module, in the 100 MHz clock domain, and passes them to the other side of the FIFO which operates in the ui_clk domain. The read FIFO accepts data from the DRAM in the ui_clk domain and the data pops out on the other side in the 100 MHz domain to be returned to the uploader module.

The flow when writing data is to have the grabword trigger the routine to push the word into the write-FIFO and then the ui_clk pump sees that valid data has arrived and uses it to drive a write into memory. When the write is confirmed by the memory interface, the ui_clk pump goes back to idle.

The flow when pulling data is to have the echoword trigger the routine to push a request into the write-FIFO. The ui_clk pump grabs the request, drives a read request to the memory interface and puts the output into the read-FIFO where it can be returned. It sets dataready on and waits until the echoword request is dropped.

2315 cartridge archiver using Diablo 31

Carl V Claunch | 17 | Version 1

Uploader module

This state machine is a simple loop, advancing word within sector within head within cylinder. On each new sector, a line is printed over the serial interface giving the cylinder, head and sector number. It then writes one line for each of the 321 words in the sector. A final line is printed with the error state of the sector.

For each word, we have generated the DRAM address using the cylinder, head, sector and word number. It raises echoword to trigger the dram_controller to read the word. When the memory content is returned, the dataready signal goes high and we drop our echoword request and move on to the next step.

The state machine formats the ASCII text for each line to be written over the serial link. We look at the value of the Cylinder, Head and Sector field and convert those into the ASCII codes for the the decimal digits. These are inserted into the buffer holding the sector address message.

This module leverages modules written by William Carter - UART_DE-BUGGER2 and YASUTX - which send ot a message stream such as the header we just formatted as well as a function to write a data word with ASCII characters for the hex value. The serial line ooperates at 115,200 baud, 1 start bit, 1 stop bit, 8 data bits and no parity.

We also format a message with codes for whether we saw a sync error or an ECC error while archiving this sector. It is transmitted after we finished the 321 words of the sector.

When we have written the error state message for the 321

st word of sector 3 of head 1 of cylinder 203, turn on the dumpdone signal to tell the too level module that the upload is complete.

2315 cartridge archiver using Diablo 31

Carl V Claunch | 18 | Version 1

Handling inputs from the disk drive to the FPGA

The disk drive terminated the disk end of the cable with a 120 ohm resistor to +5V and a 300 ohm resistor to ground. The signal line will sit about 3.6 volts when the signal is not asserted and pulled down to ground when the asserted.

On my PCB, the other end of the signal has the same 120 ohm and 300 ohm resistors. As long as the drive output gate pulls enough current to ground, the signal wore on my end will be below the logic low threshold. The wire is connected to a 74LVC125 buffer chip. The buffer is powered by a 3.3V rail produced on the PCB. The input of the buffer is tolerant of up to 5.5V thus it is safe to connect the drive signal to the chip. The chip output is 0 or 3.3V which is connected to the FPGA input pin.

Handling outputs to the disk drive from the FPGA

The disk drive end of the command signals are terminated with a 220 ohm resistor up to +5V and a 510 ohm resistor down to ground, yielding a 3.5V voltage when I am not asserting the signal. I have a 10K pullup resistor on my end of the wire and a fast MMBT2369 transistor that will pull the line down to ground to assert it.

The FPGA output pin produces a 3.3V signal to assert the output line, driving about 9ma through a 330 ohm base resistor to cause the transistor to pull the line to ground. When I drop the FPGA output to 0V, the transistor is cut off and the weak 10K resistor pulls the line up towards a 5V rail I also produce on the circuit board, but the terminator resistors on the disk drive end essentially pull the voltage to 3.5V.

2315 cartridge archiver using Diablo 31

Carl V Claunch | 19 | Version 1

Power circuits on the board

A 9V wall wart power supply feeds the circuit board. Two voltage regulators on the board are used to generate a +5V and a +3.3V rail. The +5V also feeds the Arty A7 FPGA board.

Power for the disk drive

The disk drive is powered by +15VDC and -15VDC. That operates not only the electronics in the drive, but also the motors and servo to move the disk arm. The drive consumes an average of 4A from each rail when operating and has burst requirements to about 8A.

A dedicated power supply fed from the AC mains is used to generate the high current to the drive, one each for +15 and -15. The logic and analog circuits in the drive also need +15V and -15V but they should be fed by independent power supplies to avoid noise and impedance effects from the high current devices like the motor. A third supply hooked to the AC mains is a lower current dual supply, delivering 2A of +15 and 2A of -15 to the drive.

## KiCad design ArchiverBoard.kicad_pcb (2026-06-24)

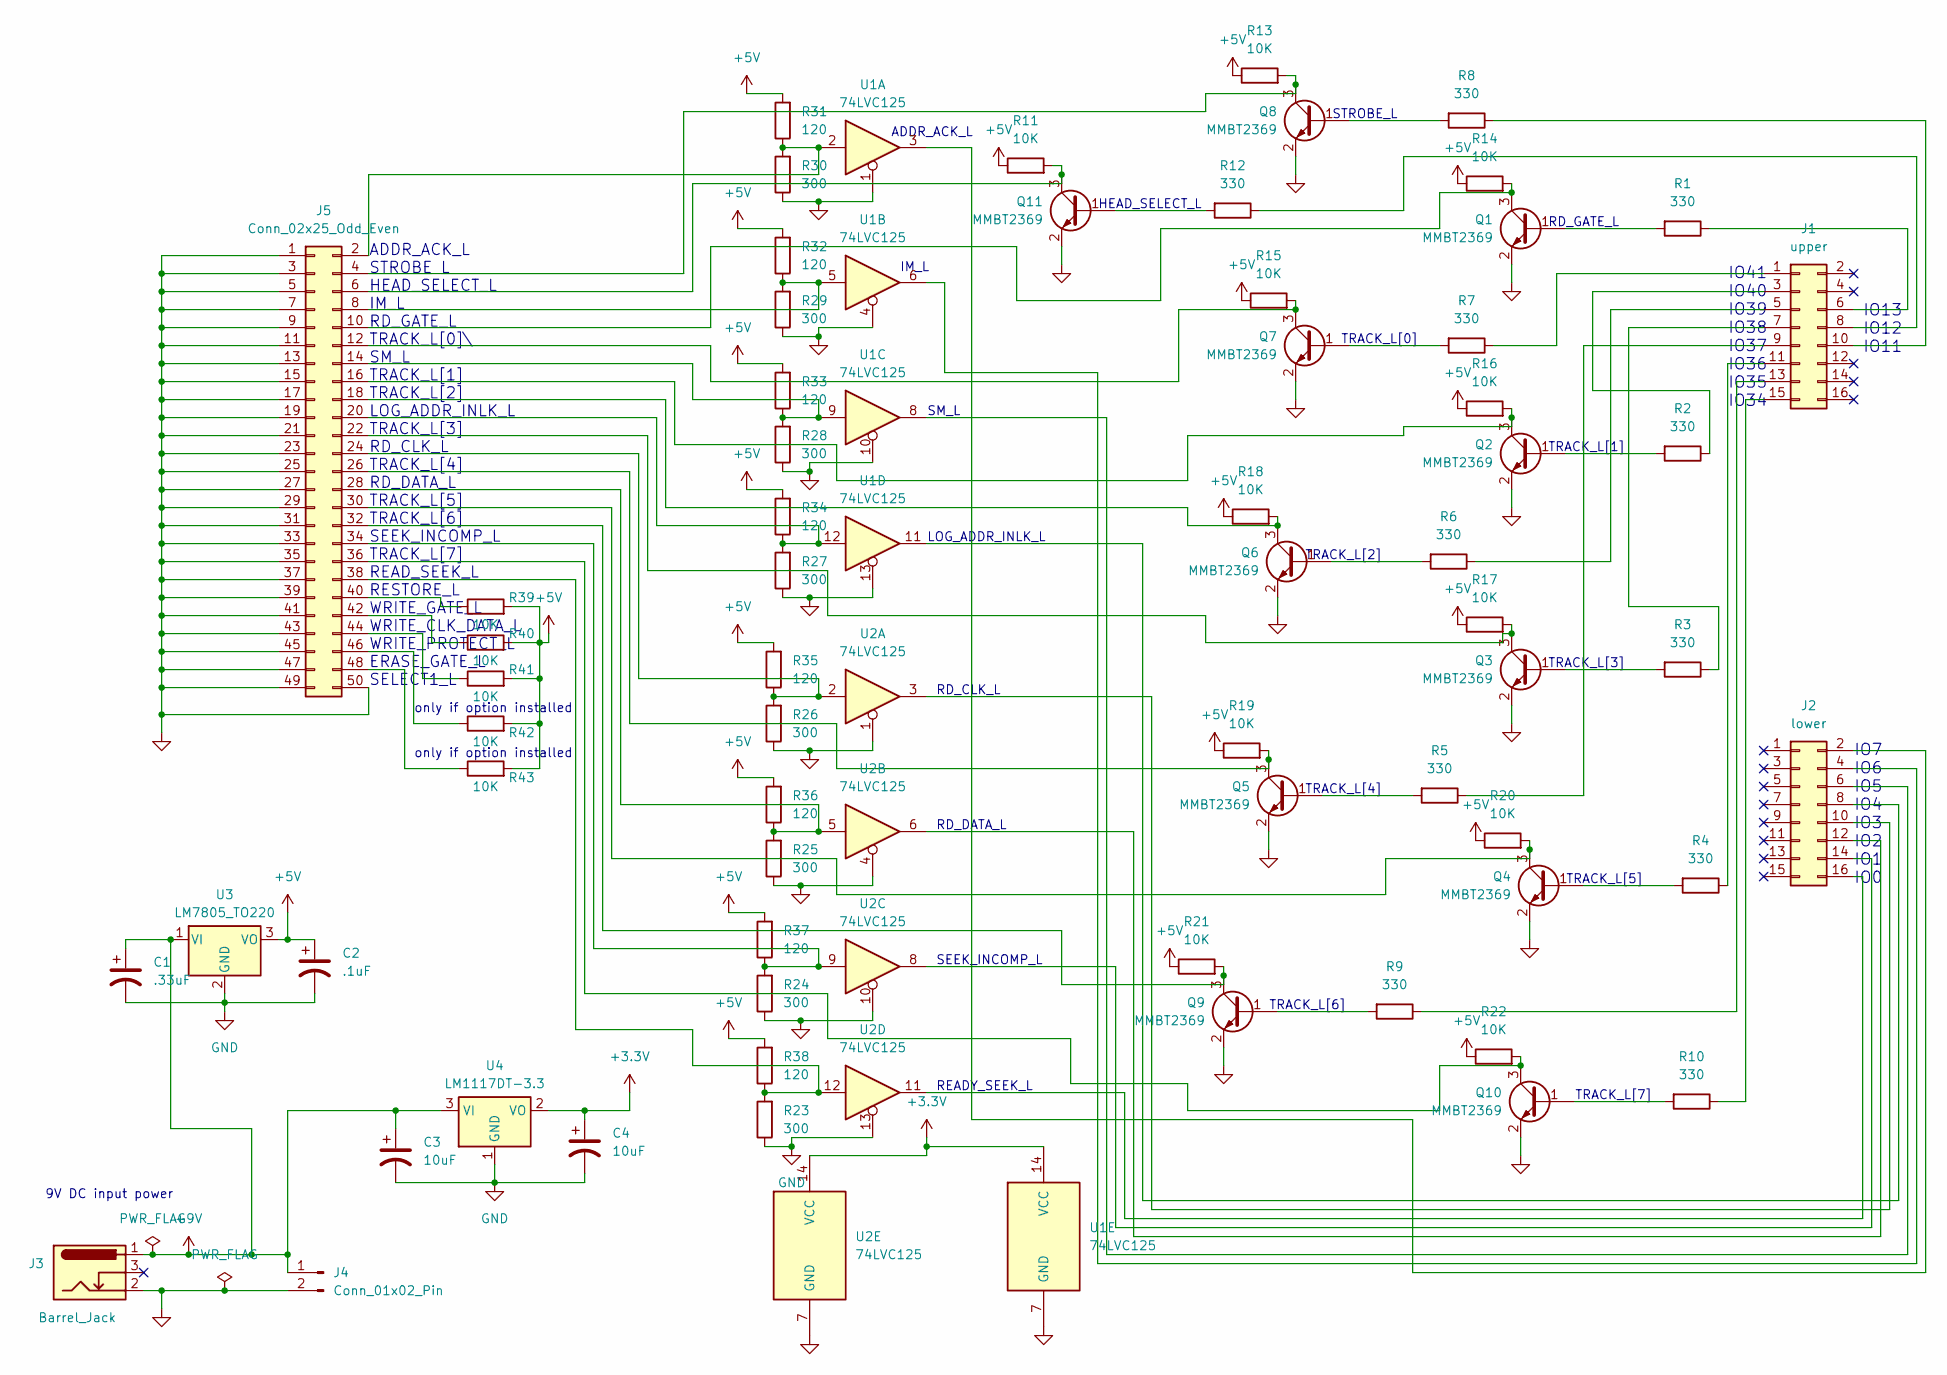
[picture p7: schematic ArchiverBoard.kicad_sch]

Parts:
C1: .33uF; C_0805_2012Metric
C2: .1uF; C_1206_3216Metric
C3, C4: 10uF; C_1206_3216Metric
J1: upper; PinHeader_2x08_P2.54mm_Vertical
J2: lower; PinHeader_2x08_P2.54mm_Vertical
J3: Barrel_Jack; BarrelJack_Kycon_KLDX-0202-xC_Horizontal
J4: Conn_01x02_Pin; PinHeader_1x02_P2.54mm_Vertical
J5: Conn_02x25_Odd_Even; IDC-Header_2x25_P2.54mm_Vertical
Q1, Q2, Q3, Q4, Q5, Q6, Q7, Q8, Q9, Q10, Q11: MMBT2369; SOT-23
R1, R2, R3, R4, R5, R6, R7, R8, R9, R10, R12: 330; R_0603_1608Metric
R11, R13, R14, R15, R16, R17, R18, R19, R20, R21, R22, R39, R40, R41, R42, R43: 10K; R_0603_1608Metric
R23, R24, R25, R26, R27, R28, R29, R30: 300; R_0603_1608Metric
R31, R32, R33, R34, R35, R36, R37, R38: 120; R_0603_1608Metric
U1, U2: 74LVC125; SO-14_3.9x8.65mm_P1.27mm
U3: LM7805_TO220; TO-220-3_Vertical
U4: LM1117DT-3.3; SOT-223

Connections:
+3.3V: C4.1, U1.14 (VCC), U2.14 (VCC), U4.2 (VO), U4.4
+5V: C2.1, R11.1, R13.1, R14.1, R15.1, R16.1, R17.1, R18.1, R19.1, R20.1, R21.1, R22.1, R31.2, R32.2, R33.2, R34.2, R35.2, R36.2, R37.2, R38.2, R39.2, R40.2, R41.2, R42.2, R43.2, U3.3 (VO)
+9V: C1.1, C3.1, J3.1, J4.1, U3.1 (VI), U4.3 (VI)
GND: C1.2, C2.2, C3.2, C4.2, J3.2, J4.2, J5.1, J5.3, J5.5, J5.7, J5.9, J5.11, J5.13, J5.15, J5.17, J5.19, J5.21, J5.23, J5.25, J5.27, J5.29, J5.31, J5.33, J5.35, J5.37, J5.39, J5.41, J5.43, J5.45, J5.47, J5.49, J5.50, Q1.2 (E), Q2.2 (E), Q3.2 (E), Q4.2 (E), Q5.2 (E), Q6.2 (E), Q7.2 (E), Q8.2 (E), Q9.2 (E), Q10.2 (E), Q11.2 (E), R23.1, R24.1, R25.1, R26.1, R27.1, R28.1, R29.1, R30.1, U1.1, U1.4, U1.7 (GND), U1.10, U1.13, U2.1, U2.4, U2.7 (GND), U2.10, U2.13, U3.2 (GND), U4.1 (GND)
unnamed: J1.1, R7.1
unnamed: J1.3, R2.1
unnamed: J1.5, R6.1
unnamed: J1.6, R1.1
unnamed: J1.7, R3.1
unnamed: J1.8, R12.1
unnamed: J1.9, R5.1
unnamed: J1.10, R8.1
unnamed: J1.11, R4.1
unnamed: J1.13, R9.1
unnamed: J1.15, R10.1
unnamed: J2.2, U1.3
unnamed: J2.4, U1.6
unnamed: J2.6, U1.8
unnamed: J2.8, U1.11
unnamed: J2.10, U2.3
unnamed: J2.12, U2.6
unnamed: J2.14, U2.8
unnamed: J2.16, U2.11
unnamed: J5.2, R30.2, R31.1, U1.2
unnamed: J5.4, Q8.3 (C), R13.2
unnamed: J5.6, Q11.3 (C), R11.2
unnamed: J5.8, R29.2, R32.1, U1.5
unnamed: J5.10, Q1.3 (C), R14.2
unnamed: J5.12, Q7.3 (C), R15.2
unnamed: J5.14, R28.2, R33.1, U1.9
unnamed: J5.16, Q2.3 (C), R16.2
unnamed: J5.18, Q6.3 (C), R18.2
unnamed: J5.20, R27.2, R34.1, U1.12
unnamed: J5.22, Q3.3 (C), R17.2
unnamed: J5.24, R26.2, R35.1, U2.2
unnamed: J5.26, Q5.3 (C), R19.2
unnamed: J5.28, R25.2, R36.1, U2.5
unnamed: J5.30, Q4.3 (C), R20.2
unnamed: J5.32, Q9.3 (C), R21.2
unnamed: J5.34, R24.2, R37.1, U2.9
unnamed: J5.36, Q10.3 (C), R22.2
unnamed: J5.38, R23.2, R38.1, U2.12
unnamed: J5.40, R39.1
unnamed: J5.42, R40.1
unnamed: J5.44, R41.1
unnamed: J5.46, R42.1
unnamed: J5.48, R43.1
unnamed: Q1.1 (B), R1.2
unnamed: Q2.1 (B), R2.2
unnamed: Q3.1 (B), R3.2
unnamed: Q4.1 (B), R4.2
unnamed: Q5.1 (B), R5.2
unnamed: Q6.1 (B), R6.2
unnamed: Q7.1 (B), R7.2
unnamed: Q8.1 (B), R8.2
unnamed: Q9.1 (B), R9.2
unnamed: Q10.1 (B), R10.2
unnamed: Q11.1 (B), R12.2

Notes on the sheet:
RD_DATA_L
RD_GATE_L
9V DC input power
ADDR_ACK_L STROBE_L HEAD_SELECT_L IM_L RD_GATE_L TRACK_L[0]\ SM_L TRACK_L[1] TRACK_L[2] LOG_ADDR_INLK_L TRACK_L[3] RD_CLK_L TRACK_L[4] RD_DATA_L TRACK_L[5] TRACK_L[6] SEEK_INCOMP_L TRACK_L[7] READ_SEEK_L RESTORE_L WRITE_GATE_L WRITE_CLK_DATA_L WRITE_PROTECT_L ERASE_GATE_L SELECT1_L
IO41 IO40 IO39 IO38 IO37 IO36 IO35 IO34
TRACK_L[7]
ADDR_ACK_L
TRACK_L[2]
TRACK_L[1]
IO13 IO12 IO11
IO7 IO6 IO5 IO4 IO3 IO2 IO1 IO0
LOG_ADDR_INLK_L
TRACK_L[5]
TRACK_L[4]
TRACK_L[6]
READY_SEEK_L
TRACK_L[0]
STROBE_L
SEEK_INCOMP_L
only if option installed
IM_L
HEAD_SELECT_L
RD_CLK_L
TRACK_L[3]
SM_L

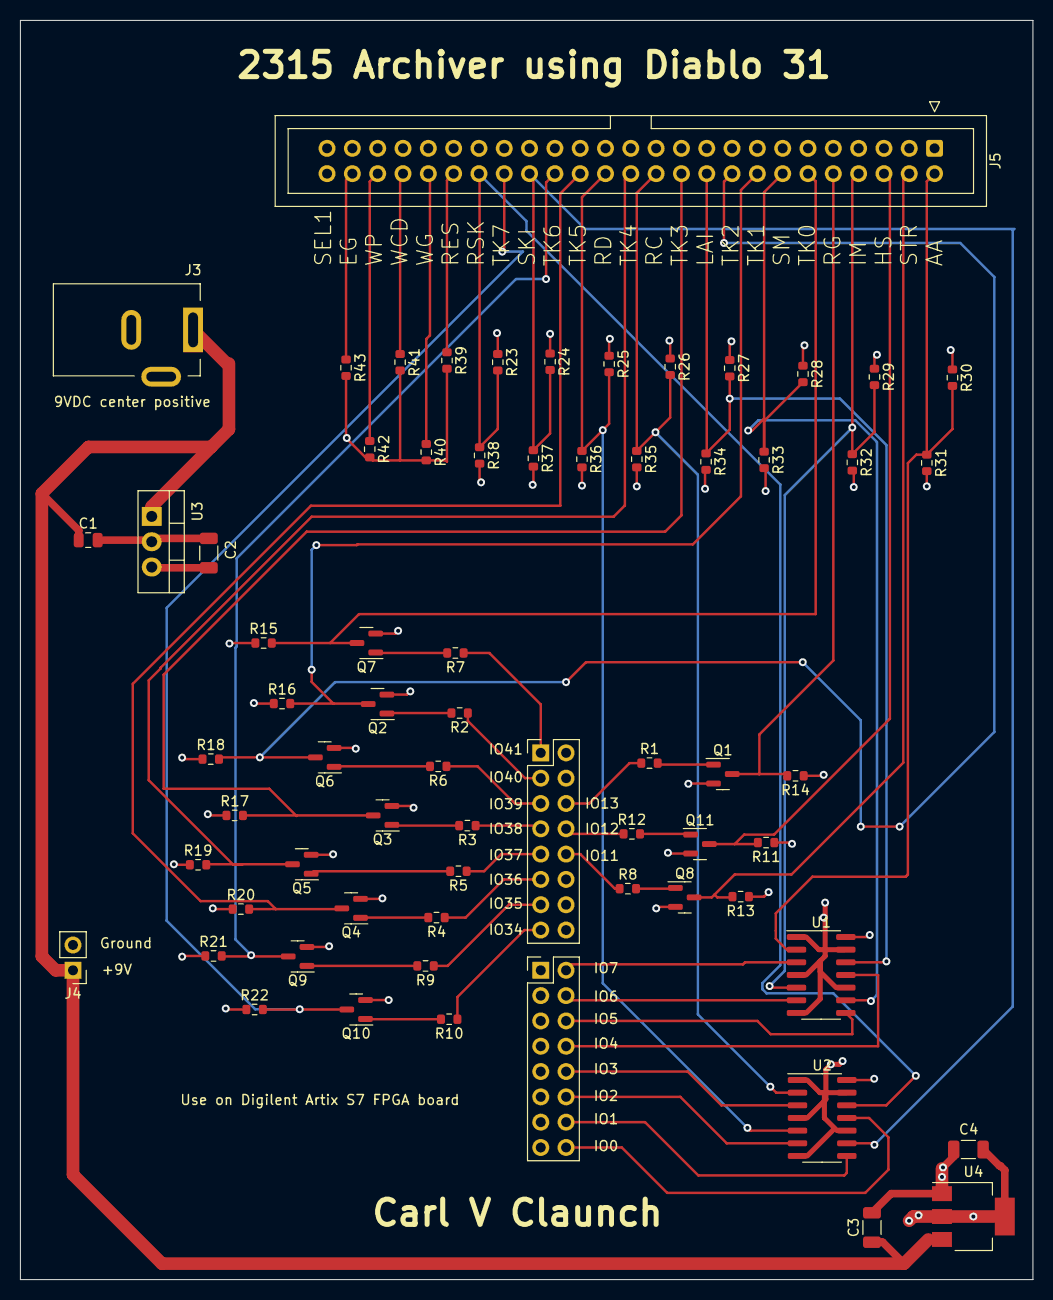
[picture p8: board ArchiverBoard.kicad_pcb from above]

Board: 4 copper layers, 101.6 x 126.3 mm, 67 parts (0 on the bottom side), 58 nets.

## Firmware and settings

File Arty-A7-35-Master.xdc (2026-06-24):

## Clock signal
set_property -dict { PACKAGE_PIN E3    IOSTANDARD LVCMOS33 } [get_ports { CLK100MHZ }]; #IO_L12P_T1_MRCC_35 Sch=gclk[100]
#create_clock -add -name CLK100MHZ -period 10.00 -waveform {0 5} [get_ports { CLK100MHZ }]; #

## Switches
set_property -dict { PACKAGE_PIN A8    IOSTANDARD LVCMOS33 } [get_ports { slideswitch }]; #IO_L12N_T1_MRCC_16 Sch=sw[0]
#set_property -dict { PACKAGE_PIN C11   IOSTANDARD LVCMOS33 } [get_ports { sw[1] }]; #IO_L13P_T2_MRCC_16 Sch=sw[1]
#set_property -dict { PACKAGE_PIN C10   IOSTANDARD LVCMOS33 } [get_ports { sw[2] }]; #IO_L13N_T2_MRCC_16 Sch=sw[2]
#set_property -dict { PACKAGE_PIN A10   IOSTANDARD LVCMOS33 } [get_ports { sw[3] }]; #IO_L14P_T2_SRCC_16 Sch=sw[3]

## RGB LEDs
set_property -dict { PACKAGE_PIN E1    IOSTANDARD LVCMOS33 } [get_ports { led0_b }]; #IO_L18N_T2_35 Sch=led0_b
set_property -dict { PACKAGE_PIN F6    IOSTANDARD LVCMOS33 } [get_ports { led0_g }]; #IO_L19N_T3_VREF_35 Sch=led0_g
set_property -dict { PACKAGE_PIN G6    IOSTANDARD LVCMOS33 } [get_ports { led0_r }]; #IO_L19P_T3_35 Sch=led0_r
set_property -dict { PACKAGE_PIN G4    IOSTANDARD LVCMOS33 } [get_ports { led1_b }]; #IO_L20P_T3_35 Sch=led1_b
set_property -dict { PACKAGE_PIN J4    IOSTANDARD LVCMOS33 } [get_ports { led1_g }]; #IO_L21P_T3_DQS_35 Sch=led1_g
set_property -dict { PACKAGE_PIN G3    IOSTANDARD LVCMOS33 } [get_ports { led1_r }]; #IO_L20N_T3_35 Sch=led1_r
set_property -dict { PACKAGE_PIN H4    IOSTANDARD LVCMOS33 } [get_ports { led2_b }]; #IO_L21N_T3_DQS_35 Sch=led2_b
set_property -dict { PACKAGE_PIN J2    IOSTANDARD LVCMOS33 } [get_ports { led2_g }]; #IO_L22N_T3_35 Sch=led2_g
set_property -dict { PACKAGE_PIN J3    IOSTANDARD LVCMOS33 } [get_ports { led2_r }]; #IO_L22P_T3_35 Sch=led2_r
set_property -dict { PACKAGE_PIN K2    IOSTANDARD LVCMOS33 } [get_ports { led3_b }]; #IO_L23P_T3_35 Sch=led3_b
set_property -dict { PACKAGE_PIN H6    IOSTANDARD LVCMOS33 } [get_ports { led3_g }]; #IO_L24P_T3_35 Sch=led3_g
set_property -dict { PACKAGE_PIN K1    IOSTANDARD LVCMOS33 } [get_ports { led3_r }]; #IO_L23N_T3_35 Sch=led3_r

## LEDs
set_property -dict { PACKAGE_PIN H5    IOSTANDARD LVCMOS33 } [get_ports { led7 }]; #IO_L24N_T3_35 Sch=led[4]
set_property -dict { PACKAGE_PIN J5    IOSTANDARD LVCMOS33 } [get_ports { led6 }]; #IO_25_35 Sch=led[5]
set_property -dict { PACKAGE_PIN T9    IOSTANDARD LVCMOS33 } [get_ports { led5 }]; #IO_L24P_T3_A01_D17_14 Sch=led[6]
set_property -dict { PACKAGE_PIN T10   IOSTANDARD LVCMOS33 } [get_ports { led4 }]; #IO_L24N_T3_A00_D16_14 Sch=led[7]

## Buttons
set_property -dict { PACKAGE_PIN D9    IOSTANDARD LVCMOS33 } [get_ports { button0 }]; #IO_L6N_T0_VREF_16 Sch=btn[0]
#set_property -dict { PACKAGE_PIN C9    IOSTANDARD LVCMOS33 } [get_ports { btn[1] }]; #IO_L11P_T1_SRCC_16 Sch=btn[1]
#set_property -dict { PACKAGE_PIN B9    IOSTANDARD LVCMOS33 } [get_ports { btn[2] }]; #IO_L11N_T1_SRCC_16 Sch=btn[2]
#set_property -dict { PACKAGE_PIN B8    IOSTANDARD LVCMOS33 } [get_ports { btn[3] }]; #IO_L12P_T1_MRCC_16 Sch=btn[3]

## Pmod Header JA
#set_property -dict { PACKAGE_PIN G13   IOSTANDARD LVCMOS33 } [get_ports { ja0 }]; #IO_0_15 Sch=ja[1]
#set_property -dict { PACKAGE_PIN B11   IOSTANDARD LVCMOS33 } [get_ports { ja1 }]; #IO_L4P_T0_15 Sch=ja[2]
#set_property -dict { PACKAGE_PIN A11   IOSTANDARD LVCMOS33 } [get_ports { ja2 }]; #IO_L4N_T0_15 Sch=ja[3]
#set_property -dict { PACKAGE_PIN D12   IOSTANDARD LVCMOS33 } [get_ports { ja3 }]; #IO_L6P_T0_15 Sch=ja[4]
#set_property -dict { PACKAGE_PIN D13   IOSTANDARD LVCMOS33 } [get_ports { ja[4] }]; #IO_L6N_T0_VREF_15 Sch=ja[7]
#set_property -dict { PACKAGE_PIN B18   IOSTANDARD LVCMOS33 } [get_ports { ja[5] }]; #IO_L10P_T1_AD11P_15 Sch=ja[8]
#set_property -dict { PACKAGE_PIN A18   IOSTANDARD LVCMOS33 } [get_ports { ja[6] }]; #IO_L10N_T1_AD11N_15 Sch=ja[9]
#set_property -dict { PACKAGE_PIN K16   IOSTANDARD LVCMOS33 } [get_ports { ja[7] }]; #IO_25_15 Sch=ja[10]

## Pmod Header JB
#set_property -dict { PACKAGE_PIN E15   IOSTANDARD LVCMOS33 } [get_ports { jb[0] }]; #IO_L11P_T1_SRCC_15 Sch=jb_p[1]
#set_property -dict { PACKAGE_PIN E16   IOSTANDARD LVCMOS33 } [get_ports { jb[1] }]; #IO_L11N_T1_SRCC_15 Sch=jb_n[1]
#set_property -dict { PACKAGE_PIN D15   IOSTANDARD LVCMOS33 } [get_ports { jb[2] }]; #IO_L12P_T1_MRCC_15 Sch=jb_p[2]
#set_property -dict { PACKAGE_PIN C15   IOSTANDARD LVCMOS33 } [get_ports { jb[3] }]; #IO_L12N_T1_MRCC_15 Sch=jb_n[2]
#set_property -dict { PACKAGE_PIN J17   IOSTANDARD LVCMOS33 } [get_ports { jb[4] }]; #IO_L23P_T3_FOE_B_15 Sch=jb_p[3]
#set_property -dict { PACKAGE_PIN J18   IOSTANDARD LVCMOS33 } [get_ports { jb[5] }]; #IO_L23N_T3_FWE_B_15 Sch=jb_n[3]
#set_property -dict { PACKAGE_PIN K15   IOSTANDARD LVCMOS33 } [get_ports { jb[6] }]; #IO_L24P_T3_RS1_15 Sch=jb_p[4]
#set_property -dict { PACKAGE_PIN J15   IOSTANDARD LVCMOS33 } [get_ports { jb[7] }]; #IO_L24N_T3_RS0_15 Sch=jb_n[4]
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

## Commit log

2026-06-23 FPGA files for the archiver logic in the Artix S7 board
2026-06-23 Picture of board from PCBWay.com as it enters production
2026-06-24 Added bill of materials and PCB files
    Gerbers as well as KiCAD schematic and PCB design
    [ArchiverBoard.kicad_pcb, ArchiverBoard.kicad_sch, BOM.xlsx]
2026-06-24 Updated documentation
    added to signals spreadsheet
    updated theory of operations manual
    updated install and operation manual
    [Signals.xlsx]
2026-06-25 SIgnals in PDF format
    spreadsheet of signal assignments
    FPGA, 50 pin connector, MRAC-42 on drive, terminators, direction, etc
2026-06-25 Updated Bill of Materials
    added items, reformatted, and shared as CSV
    [BOM.csv]
2026-06-30 Added Head Adapter tool and alignment information
    Alignment procedure, special tool to use erase coils for wider null band during alignment, and updated documentation
    [HeadAdapter.kicad_pcb, HeadAdapter.kicad_sch]
